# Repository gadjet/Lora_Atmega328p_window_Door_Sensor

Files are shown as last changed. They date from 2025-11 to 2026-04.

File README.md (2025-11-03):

# LoRa_Atmega328p_window_Door_Sensor
This repository contains the files to create the ATMEGA 328p wireles transmitter using the LoRa RX/TX chip Wio-E5.
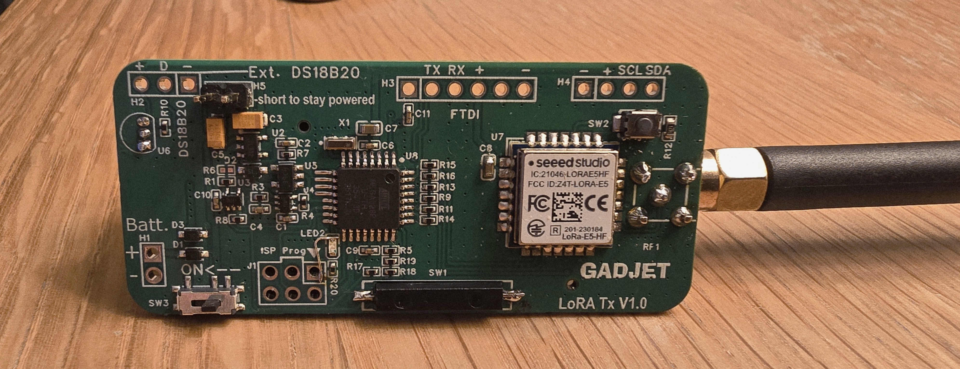
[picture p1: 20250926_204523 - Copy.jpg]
PCB image


The design uses the reed switch wakeup circuit from the earlier ESP-NOW ESP8266 based Window/Door sensor but is now controls the power supply to an ATMEGA 328p device which is then linked via the serial port to a Wio-E5 TX/RX LoRa chip from Seeedstudio.

Much the same as the WiFi based sensor this board is used to detect the status of a window or door but instead of WiFi this sensor uses 868Mhz (915MHz in other countries) to transmit the data over a much greater distance than the WiFi version.

There is also an ISP connector to allow the bootloader to be flashed into the chip but in this first version there was an error on my PCB and one of the connections was left off from the ISP connector and it requires a wire to be added to the PCB to allow flashing of the bootloader (see image).
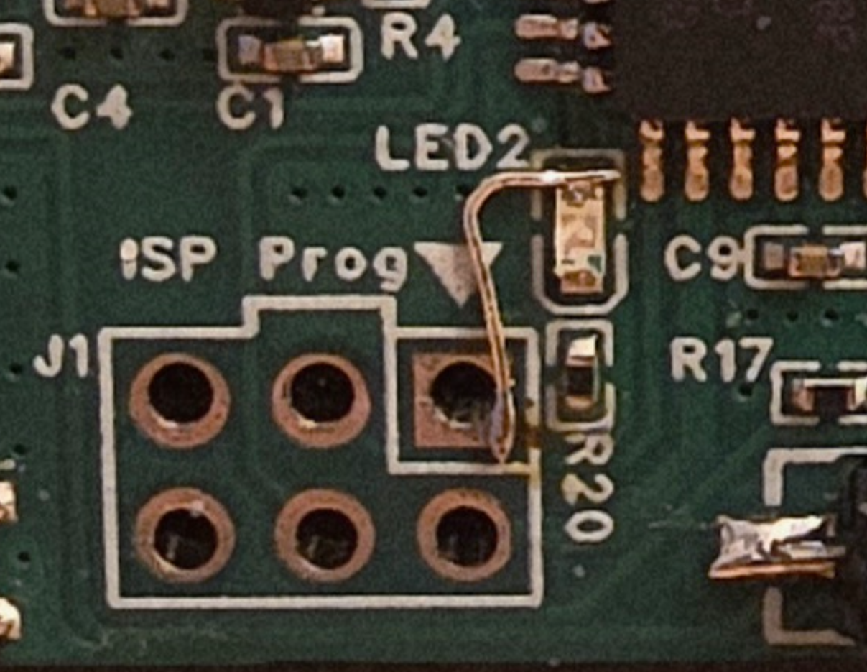
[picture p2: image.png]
PCB MOD


I also use the ISP connector to load the sketches as the serial port is connected to the WIO-E5 and seems to not work when loading the sketch via an FTDI.

I will be fixing these issues in the next version of the PCB.

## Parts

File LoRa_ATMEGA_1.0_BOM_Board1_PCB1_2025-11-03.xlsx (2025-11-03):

No. | Quantity | Comment | Designator | Footprint | Value | Manufacturer Part | Manufacturer | Supplier Part | Supplier
1 | 6 | 100nF | C1,C2,C6,C9,C10,C11 | C0402 | 100nF | CL05B104KO5NNNC | SAMSUNG(三星) | C1525 | LCSC
2 | 2 | 1uF | C3,C5 | CASE-A_3216 |  | TAJA105K035RNJ | Kyocera AVX | C7176 | LCSC
3 | 1 | 1uF | C4 | C0402 | 1uF | CL05A105KA5NQNC | SAMSUNG(三星) | C52923 | LCSC
4 | 1 | 22uF | C7 | C0603 | 22uF | CL10A226MQ8NRNC | SAMSUNG(三星) | C59461 | LCSC
5 | 1 | 4.7uF | C8 | C0603 |  | CL10A475KO8NNNC | SAMSUNG(三星) | C19666 | LCSC
6 | 3 | 1N5819WS | D1,D2,D3 | SOD-323_L1.8-W1.3-LS2.5-RD |  | 1N5819WS | Hottech(合科泰) | C191023 | LCSC
7 | 1 | KT-0603R | LED2 | LED0603-RD |  | KT-0603R | KENTO | C2286 | LCSC
8 | 5 | 1MΩ | R1,R5,R17,R18,R19 | R0402 | 1MΩ | 0402WGF1004TCE | UNI-ROYAL(厚声) | C26083 | LCSC
9 | 5 | 10kΩ | R3,R4,R7,R8,R13 | R0402 | 10kΩ | 0402WGF1002TCE | UNI-ROYAL(厚声) | C25744 | LCSC
10 | 3 | 4.7kΩ | R9,R10,R11 | R0402 | 4.7kΩ | 0402WGF4701TCE | UNI-ROYAL(厚声) | C25900 | LCSC
11 | 1 | 470Ω | R12 | R0603 |  | 0603WAF4700T5E | UniOhm | C23179 | LCSC
12 | 3 | 22Ω | R14,R15,R16 | R0402 | 22Ω | 0402WGF220JTCE | UNI-ROYAL(厚声) | C25092 | LCSC
13 | 1 | 1kΩ | R20 | R0402 | 1kΩ | 0402WGF1001TCE | UNI-ROYAL(厚声) | C11702 | LCSC
14 | 1 | TSA343G00D-250J2 | SW2 | SW-SMD_L4.0-W2.9-P4.15-EH |  | TSA343G00D-250J2 | BRIGHT(博瑞泰) | C354947 | LCSC
15 | 1 | MSS12C02LS-HB2.0 | SW3 | SW-SMD_MSS12C02LS-HB2.0-1 |  | MSS12C02LS-HB2.0 | SHOU HAN(首韩) | C3008584 | LCSC
16 | 1 | SPX3819M5-L-3-3/TR | U2 | SOT-23-5_L3.0-W1.7-P0.95-LS2.8-BL |  | SPX3819M5-L-3-3/TR | MaxLinear | C9055 | LCSC
17 | 2 | 74AHC1G86GW,125 | U3,U4 | SOT-353-5_L2.0-W1.3-P0.65-LS2.1-BR |  | 74AHC1G86GW,125 | Nexperia(安世) | C554319 | LCSC
18 | 1 | SN74AHC1G32DBVR | U5 | SOT-23-5_L3.0-W1.7-P0.95-LS2.8-BR |  | SN74AHC1G32DBVR | TI(德州仪器) | C7470 | LCSC
19 | 1 | ATMEGA328P-AU | U8 | TQFP-32_L7.0-W7.0-P0.80-LS9.0-BL |  | ATMEGA328P-AU | MICROCHIP(美国微芯) | C14877 | LCSC
20 | 1 | 16MHz | X1 | OSC-SMD_3P-L3.2-W1.3-P1.20-L | 16MHz | CSTNE16M0V53L000R0 | muRata(村田) | C1870467 | LCSC

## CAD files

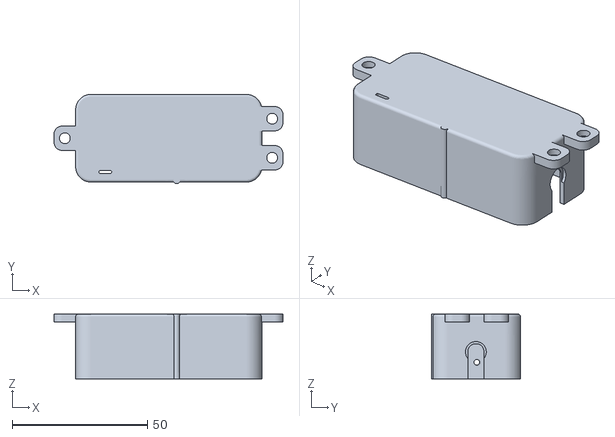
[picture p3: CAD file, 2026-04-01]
Enclosure_Base.stl
84.8 x 33.0 x 24.0

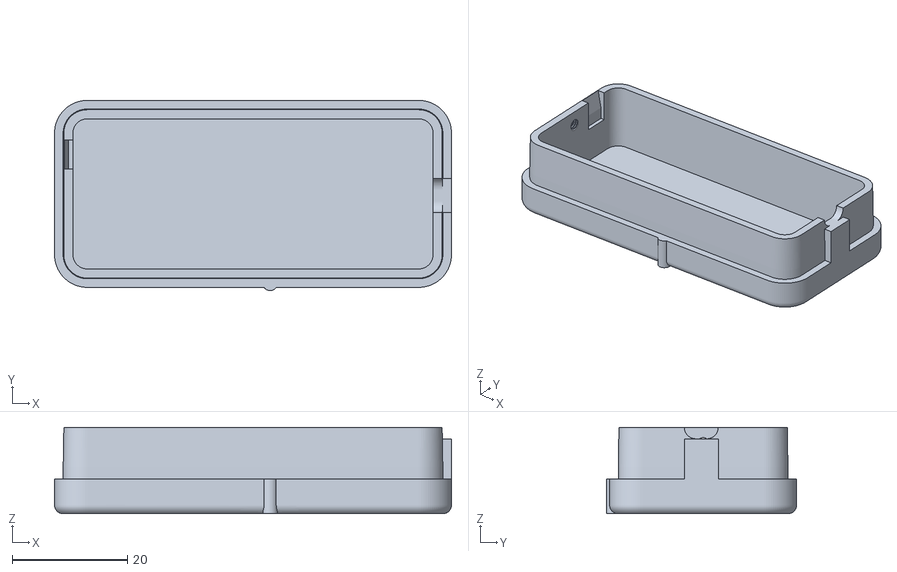
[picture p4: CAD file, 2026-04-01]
Enclosure_top.stl
68.9 x 33.0 x 15.0

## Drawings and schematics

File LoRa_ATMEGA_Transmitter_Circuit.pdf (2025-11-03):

# Voltage Regulator

# Wakeup circuit

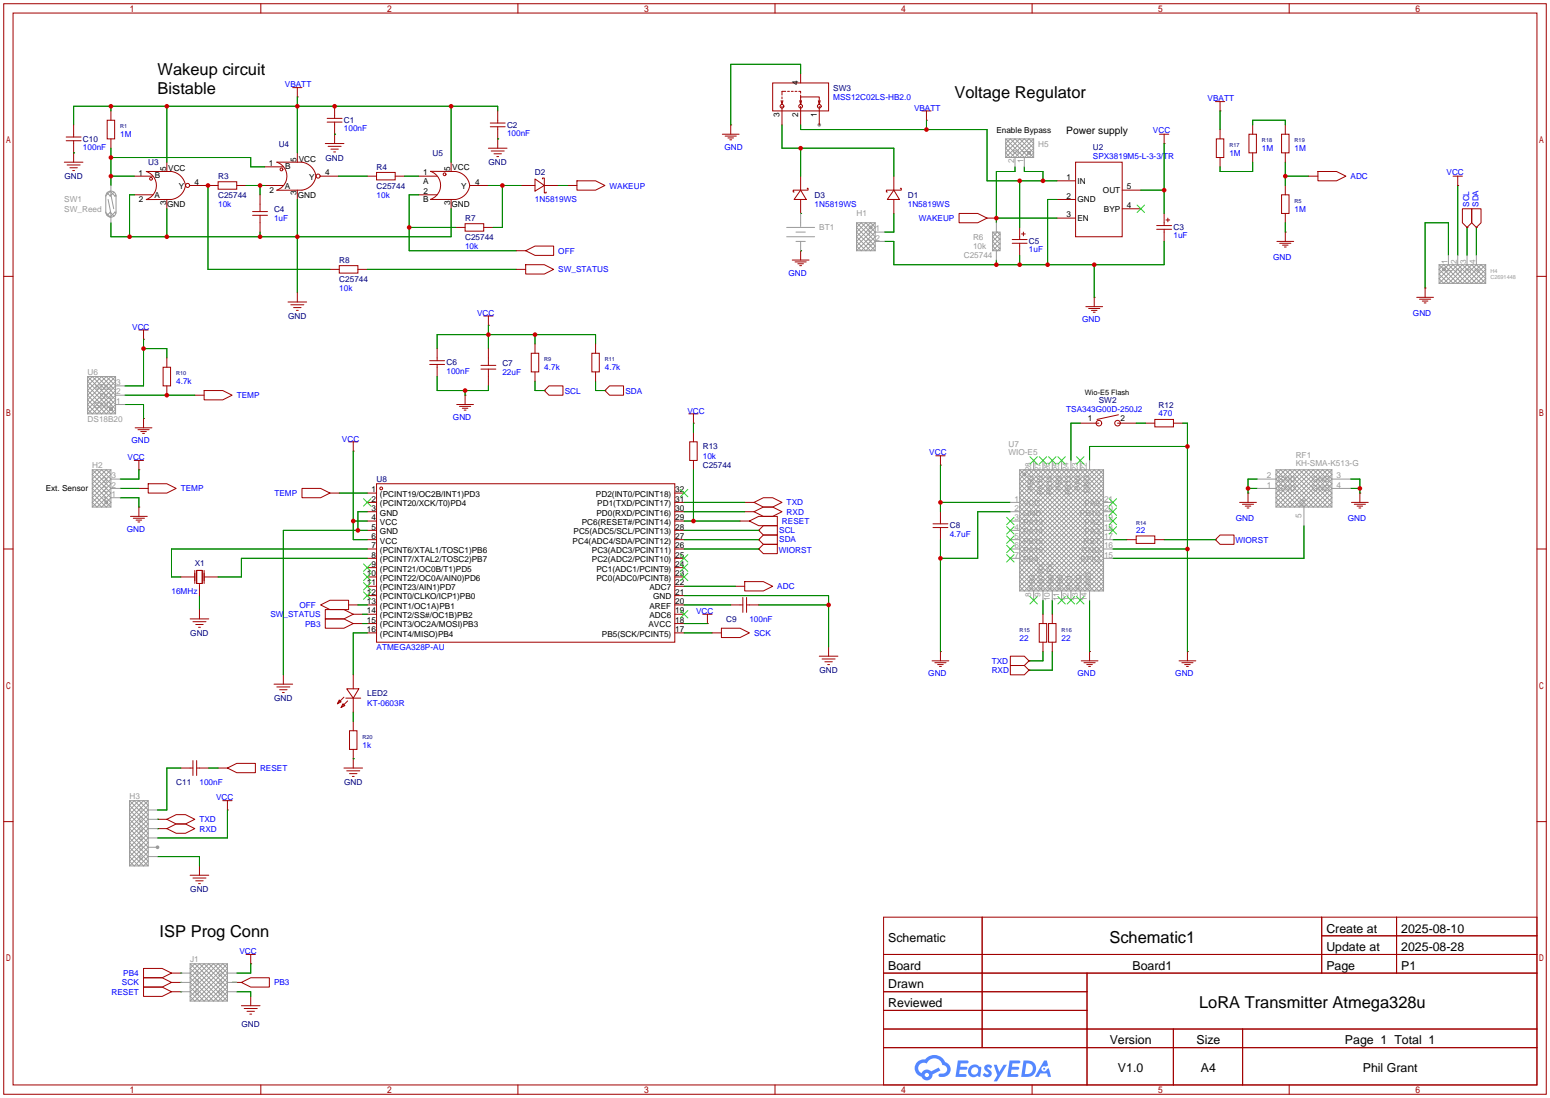
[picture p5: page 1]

Schematic | Schematic1 | Create at | 2025-08-10

Update at | 2025-08-28

Board | Board1 | Page | P1
Drawn | | LoRA Transmitter Atmega328u
Reviewed

Version | Size | Page 1 Total 1
V1.0 | A4 | Phil Grant

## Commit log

2025-11-03 Add files via upload
    PCB MOD to fix ISP programming
2025-11-03 Update README.md
    Added images and details of issues with version 1 of the PCB
2025-11-03 Add files via upload
    Circuit Schematic
2025-11-03 Add files via upload
    PCB Gerber files
2025-11-03 Add files via upload
    Added PCB BOM file
    [LoRa_ATMEGA_1.0_BOM_Board1_PCB1_2025-11-03.xlsx]
2025-11-03 Add files via upload
    PCB Pick and place files
    [LoRa_ATMEGA_1.0_PickAndPlace_PCB1_2025-11-03.xlsx]
2026-04-01 Add files via upload
    Enclosure 3D STL files added
    [Enclosure_Base.stl, Enclosure_top.stl]
